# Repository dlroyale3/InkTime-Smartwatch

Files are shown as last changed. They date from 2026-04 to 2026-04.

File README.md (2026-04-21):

# Proiect InkTime - E-Paper Smartwatch (nRF52840)

## Descriere Generală
InkTime este un prototip hardware de smartwatch (dispozitiv wearable) proiectat de la zero, cu un focus absolut pe eficiența energetică (Ultra-Low Power) și miniaturizare. 
Creierul sistemului este SoC-ul **Nordic nRF52840**, capabil de conectivitate Bluetooth 5.0 LE. Dispozitivul interacționează cu utilizatorul printr-un ecran E-Paper de 3.3V (tehnologie bistabilă), butoane tactile și feedback haptic (motor liniar/ERM), fiind capabil să monitorizeze activitatea fizică prin intermediul unui accelerometru integrat.

---

## 1. Diagramă Bloc

Arhitectura hardware este centrată în jurul microcontrolerului, care acționează ca un Master I2C/SPI pentru toate perifericele, permițând controlul granular al stărilor de alimentare pentru fiecare modul în parte.

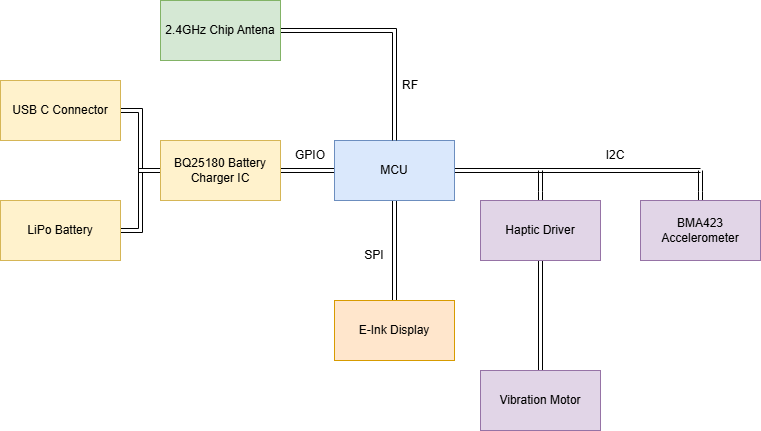
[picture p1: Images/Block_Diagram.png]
Diagrama Bloc InkTime


---

## 2. Bill of Materials (BOM) - Componente Principale

Pentru producția și asamblarea PCB-ului (PCBA), componentele au fost selectate pe baza disponibilității la producătorul JLCPCB (LCSC Parts) și a footprint-ului redus (QFN, BGA sau 0402/0201 pentru pasive).

| Componentă (Designator) | Rol în Sistem | Producător | Datasheet | Link JLCPCB |
| :--- | :--- | :--- | :--- | :--- |
| **nRF52840-QIAA** (U1) | Microcontroller & BLE Radio | Nordic Semi | [Datasheet](https://infocenter.nordicsemi.com/pdf/nRF52840_PS_v1.7.pdf) | [C145322](https://jlcpcb.com/partdetail/NordicSemicon-nRF52840QIAAR/C145322) |
| **BQ25180YBGR** (IC1) | LiPo Battery Charger | Texas Instruments | [Datasheet](https://www.ti.com/lit/ds/symlink/bq25180.pdf) | [C3166611](https://jlcpcb.com/partdetail/TexasInstruments-BQ25180YBGR/C3166611) |
| **MAX17048G+T10** (U3) | Fuel Gauge (Monitor Baterie) | Analog Devices | [Datasheet](https://www.analog.com/media/en/technical-documentation/data-sheets/MAX17048-MAX17049.pdf) | [C82806](https://jlcpcb.com/partdetail/Maxim_Integrated-MAX17048GT10/C82806) |
| **RT6160AWSC** (IC9) | DC/DC Buck-Boost Converter | Richtek | [Datasheet](https://www.richtek.com/assets/product_file/RT6160A/DS6160A-02.pdf) | [C2834316](https://jlcpcb.com/parts) |
| **BMA423 / BMA421** (IC3) | Accelerometru Triaxial (IMU) | Bosch Sensortec | [Datasheet](https://www.bosch-sensortec.com/media/boschsensortec/downloads/datasheets/bst-bma423-ds004.pdf) | [C283838](https://jlcpcb.com/partdetail/BoschSensortec-BMA423/C283838) |
| **DRV2605YZFR** (IC2) | Haptic Driver (LRA/ERM) | Texas Instruments | [Datasheet](https://www.ti.com/lit/ds/symlink/drv2605.pdf) | [C74431](https://jlcpcb.com/partdetail/TexasInstruments-DRV2605YZFR/C74431) |
| **2450AT18B100E** (ANT1)| Antenă Ceramică 2.4 GHz | Johanson Tech | [Datasheet](https://www.johansontechnology.com/datasheets/2450AT18B100/2450AT18B100.pdf) | [C210086](https://jlcpcb.com/partdetail/JohansonTechnology-2450AT18B100E/C210086) |

*(Notă: Componentele pasive - rezistențe și condensatori de 0201/0402, inductoarele de putere și conectorii USB-C/FPC se regăsesc detaliate în fișierul `BOM.csv` din folderul Manufacturing).*

---

## 3. Funcționalitate Hardware Detaliată

Sistemul a fost împărțit în mai multe subsisteme, optimizate pentru a permite oprirea alimentării (Power Gating) atunci când nu sunt utilizate.

### 3.1. Procesare și Radio (nRF52840)
MCU-ul rulează la o tensiune stabilizată de 3.3V. Pentru a menține timing-ul BLE și RTC-ul (Real Time Clock) cu un consum de doar ~1.5µA, a fost integrat un cristal extern de 32.768 kHz (`X2`). Conexiunea radio se face printr-o rețea Pi-Matching către antena ceramică de 2.4GHz.

### 3.2. Magistrala I2C și Senzorii
Toate perifericele de monitorizare și input folosesc o magistrală comună **I2C** (Fast Mode - 400kHz), echipată cu rezistențe de pull-up de 10kΩ.
* **BMA423 (IMU - 0x18):** Configurabil să ruleze algoritmul de *step-counting* intern. Nu ține MCU-ul treaz; trimite un semnal pe pinul `IMU_INT1` doar când detectează pași sau gesturi (Tilt-to-Wake).
* **MAX17048 (Fuel Gauge - 0x36):** Estimează starea bateriei (State of Charge) fără a necesita o rezistență de șunt (care ar irosi energie), folosind algoritmul ModelGauge. Poate genera o alertă hardware (`ALERT`) când bateria scade sub un prag definit.
* **BQ25180 (Charger - 0x6A):** Negociază curentul de încărcare tras din portul USB-C (limitat software la 100mA - 300mA pentru a proteja celula LiPo mică).
* **DRV2605 (Haptic - 0x5A):** Conține o bibliotecă internă de forme de undă pentru vibrații. Este ținut în shutdown (consum <1µA) și activat doar la notificări prin pinul `HAPTIC_EN`.

### 3.3. Display-ul E-Paper (SPI)
Interfața vizuală folosește un panou bistabil conectat printr-un cablu FPC 24-pin.
* **Comunicația:** Se face via **SPI 4-wire** (doar TX/MOSI, deoarece ecranul nu trimite date înapoi, ci folosește un pin dedicat `EPD_BUSY` pentru a semnaliza starea).
* **Boost Circuit:** Deoarece cerneala electronică necesită tensiuni mari (VGH, VGL, +/- 15V) pentru a muta pigmenții, placa include circuitul de switching cu inductor de 68uH și diode Schottky MBR0530. Acest circuit este pornit exclusiv în secunda în care ecranul își dă refresh.

### 3.4. Calcule de Consum de Energie (Power Budget)
Eficiența proiectului se bazează pe regimul de funcționare *Duty-Cycled*. Estimarea autonomiei cu o baterie LiPo de **150 mAh**:

1. **Modul Deep Sleep (98% din timp):**
   * nRF52840 (System ON, RTC): ~1.5 µA
   * BMA423 (Low-power sensing): ~4 µA
   * BQ25180 + RT6160 (Quiescent): ~8 µA
   * Fuel Gauge (Hibernate): ~3 µA
   * Ecran E-Paper: 0 µA
   * **Total Sleep:** **~16.5 µA**

2. **Modul Activ (Evenimente periodice):**
   * Refresh Ecran (1 dată pe minut): ~8 mA timp de 1s.
   * Transmisie BLE: ~5 mA timp de 10ms.
   * **Consum Mediu Echivalent:** **~1.2 mA / oră** (incluzând spike-urile de refresh).

3. **Autonomie Teoretică:** `150 mAh / 1.2 mA ≈ 125 de ore (aprox. 5 zile)` de utilizare normală, cu potențial de extindere până la **săptămâni** dacă ecranul este actualizat doar la cerere (button press).

---

## 4. Alocarea Pinilor nRF52840 și Justificare

Rutarea pinilor (Pin Muxing) a fost aleasă strategic pentru a evita încrucișările pe PCB și pentru a grupa interfețele de mare viteză.

| Pin MCU | Funcție Atribuită | Tip Interfață | Justificarea Alegerii (Hardware Design) |
| :--- | :--- | :--- | :--- |
| **P0.00 / P0.01** | `XL1` / `XL2` | Analog | Pini dedicați hardware exclusiv pentru cristalul LFXO (32.768kHz). |
| **P0.06 / P0.07** | `SDA` / `SCL` | I2C (TWIM) | Plasați convenabil pe latura de jos a IC-ului, rutare directă spre grupul de senzori (Bottom). |
| **P0.08 / P1.08** | `IMU_INT1` / `IMU_INT2`| GPIO (Interrupt) | Intrări cu capacitate de *Wake-up*, conectate direct la accelerometru. |
| **P0.02 / P0.03** | `SCK` / `MOSI` | SPI (SPIM) | Alocați pentru a minimiza distanța fizică a traseelor de mare viteză către conectorul FPC al ecranului (partea dreaptă a plăcii). |
| **P0.17** | `EPD_BUSY` | GPIO (Input) | Citește flag-ul de busy de la ecran. Permite MCU-ului să doarmă între comenzile SPI. |
| **P1.06** | `HAPTIC_EN` | GPIO (Output) | Semnal digital simplu (Enable) pentru a tăia alimentarea driverului de vibrații. |
| **P1.01 / P1.02 / P1.03** | `SW_UP/DN/ENT` | GPIO (Input) | Pini configurați cu rezistențe de pull-up interne/externe pentru debounce-ul mecanic al butoanelor. |
| **SWDIO / SWDCLK** | Debug / Flash | SWD | Pini hardwired pentru programarea via conectorul TC2030-IDC. |

---

## 5. Design Log & PCB Layout (4-Layer Stackup)

PCB-ul a fost proiectat pe 4 straturi pentru a asigura plane solide de referință (GND), necesare disipării termice și integrității semnalului RF. 
S-a implementat o matrice de **Via Stitching** în jurul secțiunii de radiofrecvență și un decupaj (Polygon Cutout) pe toate cele 4 straturi sub antena Johanson, pentru a preveni atenuarea undelor electromagnetice.

* **Layer 1 (Top):** Găzduiește toate componentele SMD, planul de masă (GND) primar și traseele critice de scurtă distanță.
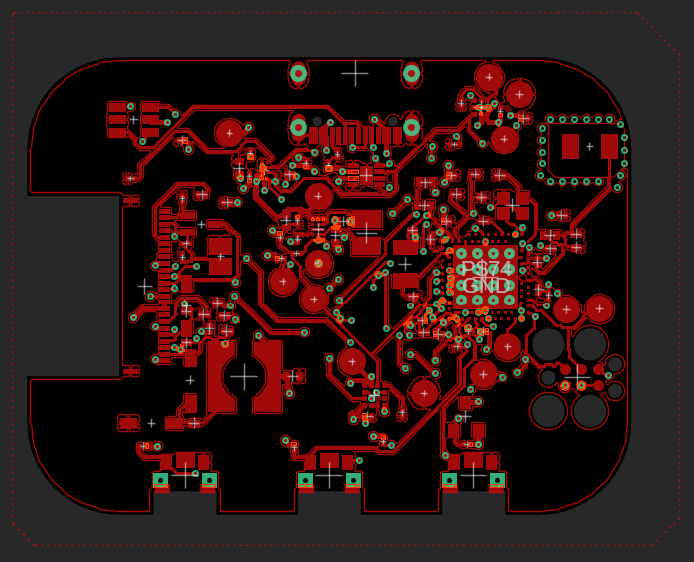
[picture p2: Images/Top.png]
Top Layer


* **Layer 2 (Route2 / Inner GND):** Strat intern dedicat exclusiv unui plan de masă continuu (Solid Ground Plane). Acesta oferă o cale de întoarcere curată și scurtă pentru curenți, esențială pentru ecranarea zgomotului (EMI) și performanța antenei.

* **Layer 3 (Route63 / Inner Power):** Strat intern dedicat rețelelor de distribuție a puterii (`3V3`, `VBUS`, `VBAT`, `VREG`). Traseele au o lățime minimă de 0.3mm pentru a menține o impedanță redusă și a preveni căderile de tensiune la solicitări tranzitorii.
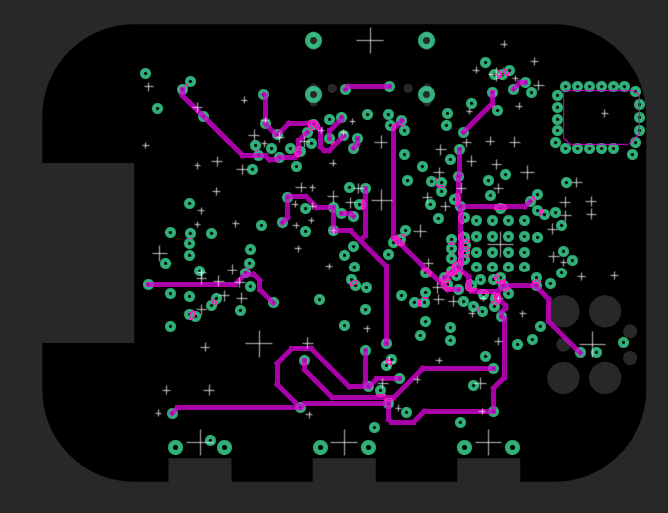
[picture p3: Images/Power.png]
Power Layer


* **Layer 4 (Bottom):** Utilizat preponderent pentru rutarea magistralelor de date (ex: `I2C`) și pentru realizarea conexiunilor lungi care ar fi aglomerat fața Top. Dispune, de asemenea, de propriul plan de masă auxiliar.
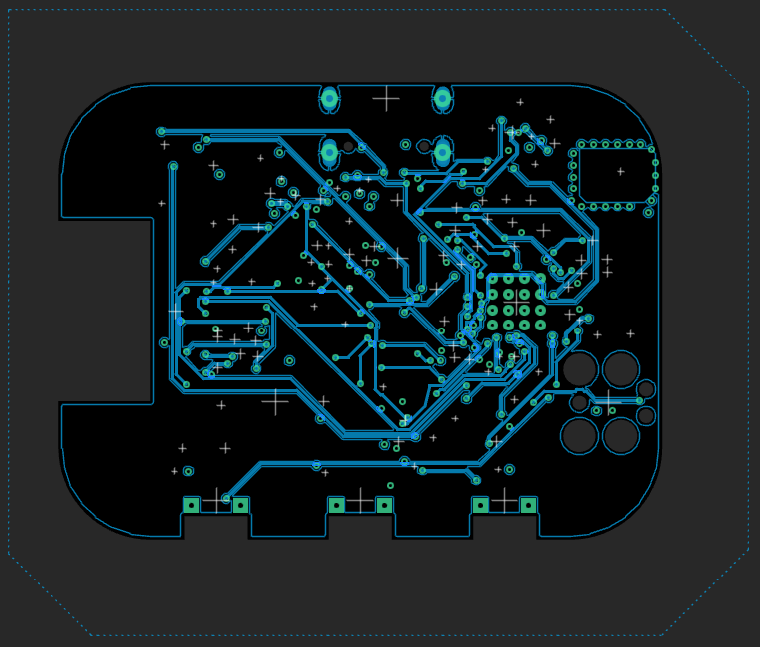
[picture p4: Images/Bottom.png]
Bottom Layer


### Testabilitate și Producție
Placa dispune de **Test Pad-uri** dedicate pentru toate semnalele critice (`3V3`, `VBAT`, `SDA`, `SCL`, `SWDIO`), etichetate clar pe layer-ul de Silkscreen, permițând depanarea facilă cu osciloscopul sau analizorul logic după asamblare.
### Testabilitate și Producție
Placa dispune de **Test Pad-uri** dedicate pentru toate semnalele critice (`3V3`, `VBAT`, `SDA`, `SCL`, `SWDIO`), etichetate clar pe layer-ul de Silkscreen, permițând depanarea facilă cu osciloscopul sau analizorul logic după asamblare.

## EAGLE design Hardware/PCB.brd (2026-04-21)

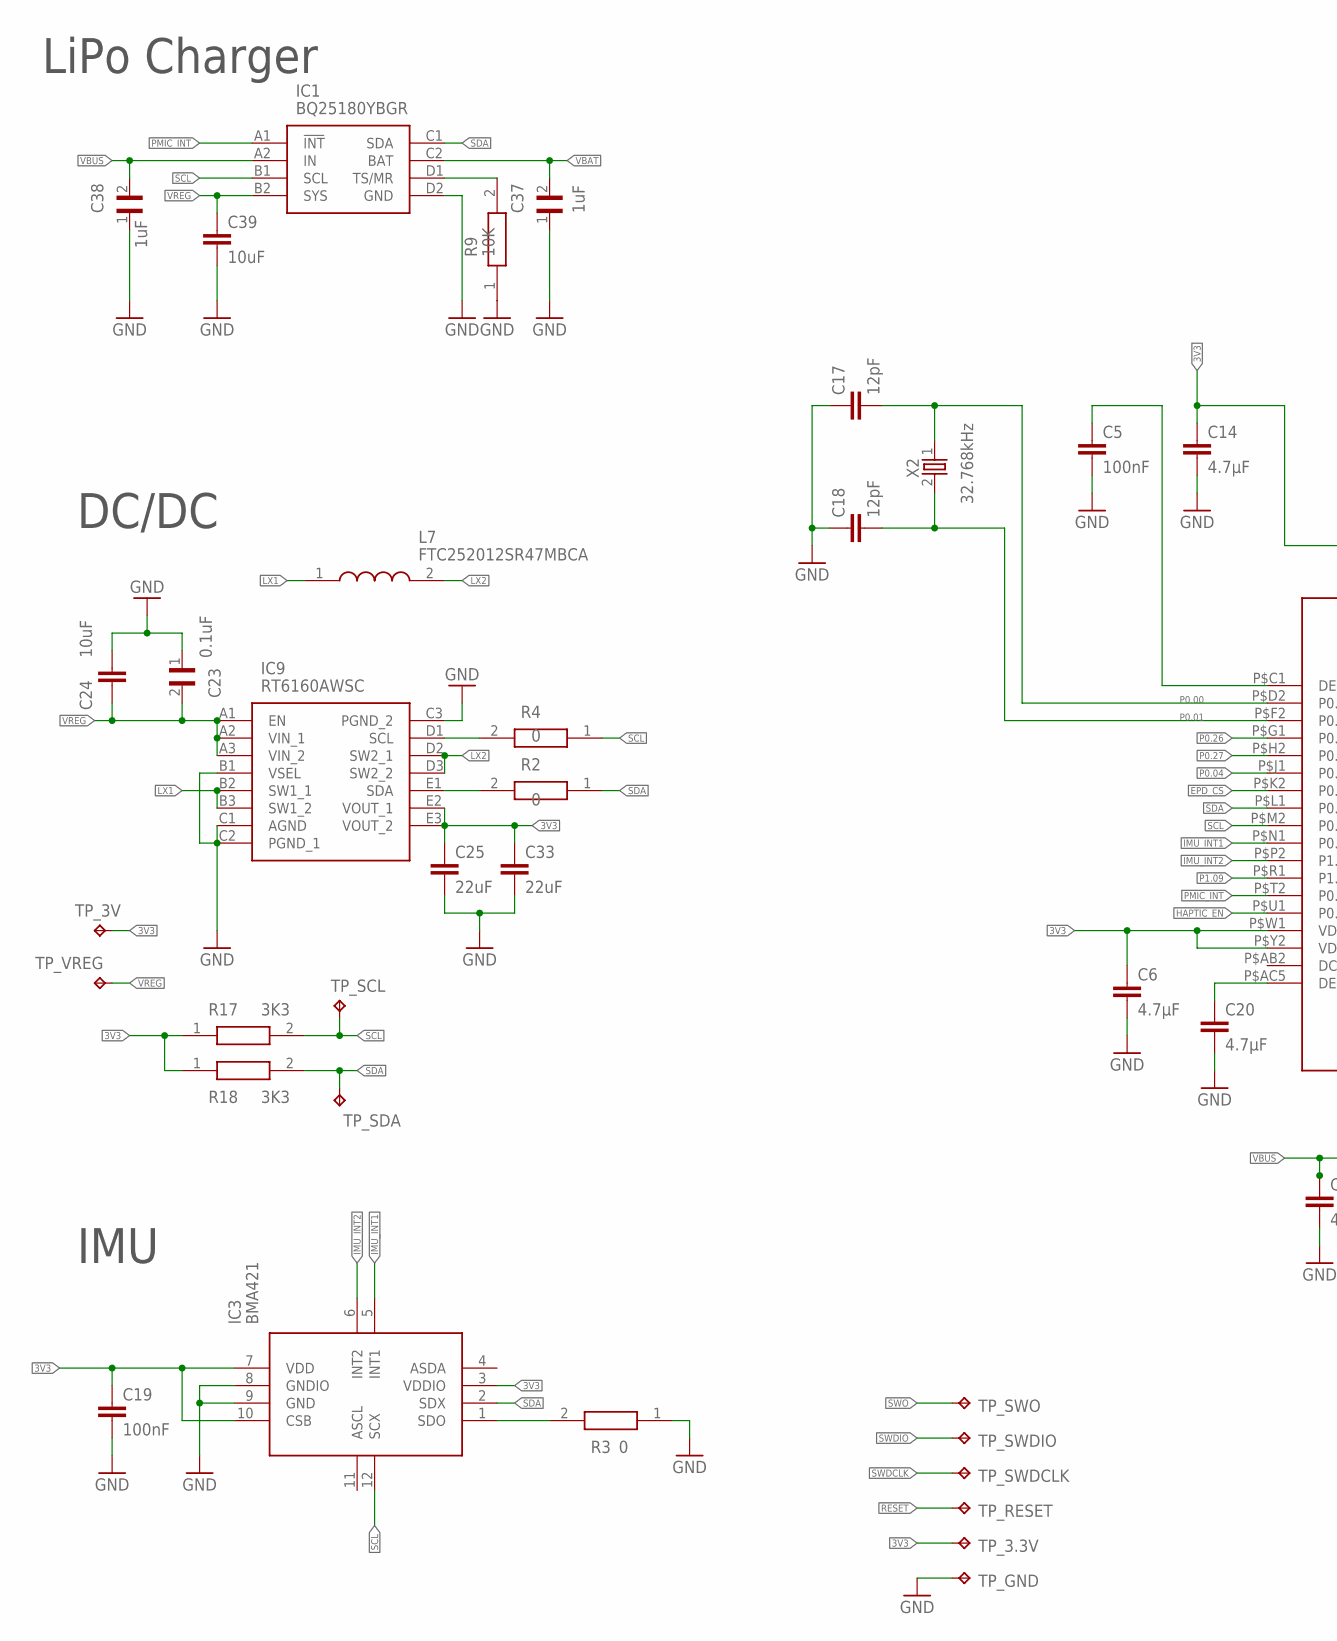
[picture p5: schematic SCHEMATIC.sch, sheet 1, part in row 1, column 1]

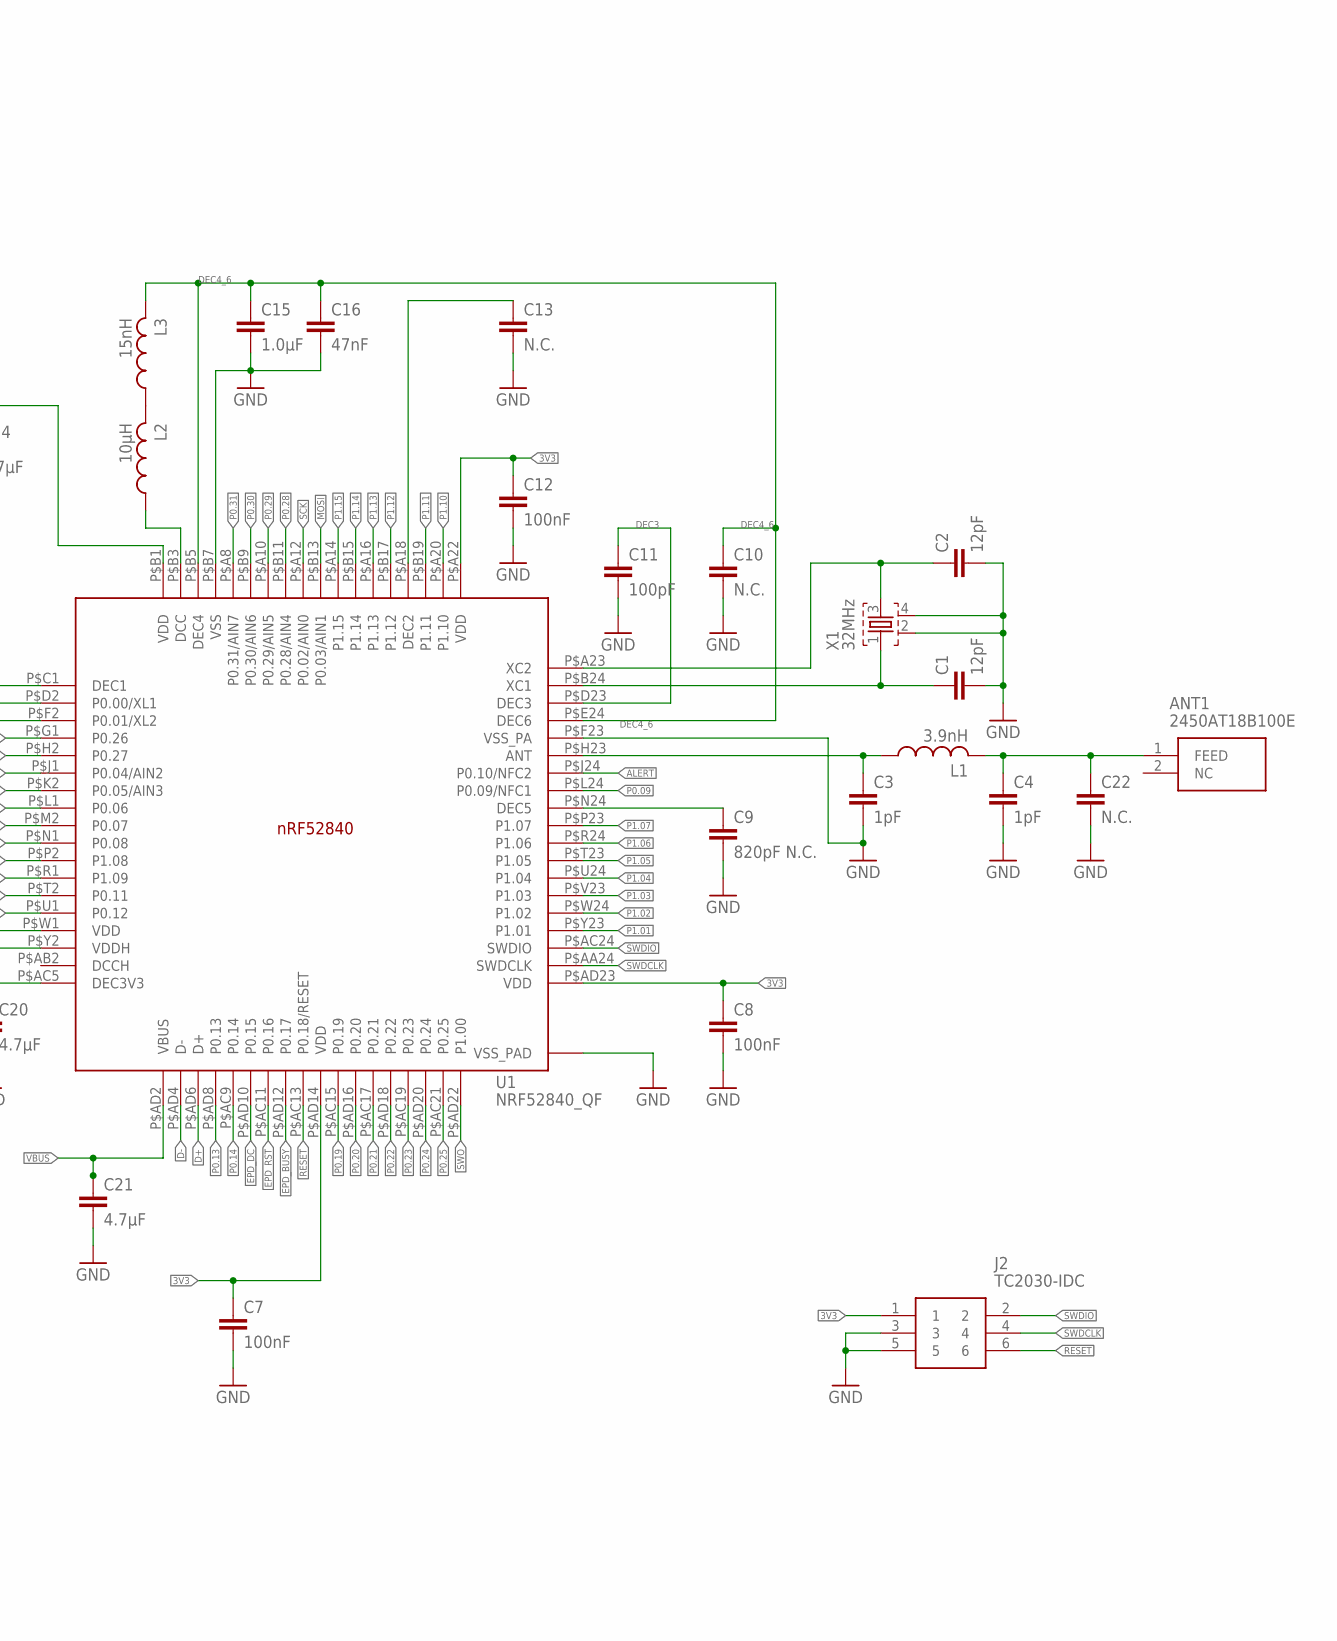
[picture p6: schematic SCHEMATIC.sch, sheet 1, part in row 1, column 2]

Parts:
ANT1: 2450AT18B100E; 2450AT18B100E_ANTC3216X140N
C1, C2, C17, C18: 12pF; NORDIC_NRF_3_RESC0201_L
C3, C4: 1pF; NORDIC_NRF_3_RESC0201_L
C5, C7, C8, C12, C19: 100nF; NORDIC_NRF_3_RESC0201_L
C6, C14, C20, C21: 4.7µF; NORDIC_NRF_3_RESC0201_L
C9: 820pF N.C.; NORDIC_NRF_3_RESC0201_L
C10, C13, C22: N.C.; NORDIC_NRF_3_RESC0201_L
C11: 100pF; NORDIC_NRF_3_RESC0201_L
C15: 1.0µF; NORDIC_NRF_3_RESC0201_L
C16: 47nF; NORDIC_NRF_3_RESC0201_L
C23: 0.1uF; GRM011R60J152KE01L_1_0201
C24, C39: 10uF; NORDIC_NRF_3_RESC0402_L
C25, C33: 22uF; NORDIC_NRF_3_RESC0402_L
C37, C38: 1uF; GRM011R60J152KE01L_1_0201
IC1: BQ25180YBGR; BQ25180YBGR_BGA8C40P2X4_100X155X50
IC3: BMA421; BMA423_BMA423
IC9: RT6160AWSC; RT6160AWSC_BGA15C40P3X5_140X230X60
J2: TC2030-IDC; TC2030-IDC_TC2030IDC
L1: 3.9nH; NORDIC_NRF_2_RESC0402_L
L2: 10µH; NORDIC_NRF_2_RESC0402_L
L3: 15nH; NORDIC_NRF_2_RESC0402_L
L7: FTC252012SR47MBCA; MLP2016SR47MT0S1_INDC2016X100N
R2, R3, R4: 0; CPF0201D7K68C1_0201
R9: 10K; CPF0201D7K68C1_0201
R17, R18: 3K3; CPF0201D7K68C1_0201
TP_3.3V, TP_3V: HECTOR_WATCH_1_TPTP20R; HECTOR_WATCH_1_TP20R
TP_GND: HECTOR_WATCH_1_TPTP20R; HECTOR_WATCH_1_TP20R
TP_RESET: HECTOR_WATCH_1_TPTP20R; HECTOR_WATCH_1_TP20R
TP_SCL: HECTOR_WATCH_1_TPTP20R; HECTOR_WATCH_1_TP20R
TP_SDA: HECTOR_WATCH_1_TPTP20R; HECTOR_WATCH_1_TP20R
TP_SWDCLK: HECTOR_WATCH_1_TPTP20R; HECTOR_WATCH_1_TP20R
TP_SWDIO: HECTOR_WATCH_1_TPTP20R; HECTOR_WATCH_1_TP20R
TP_SWO: HECTOR_WATCH_1_TPTP20R; HECTOR_WATCH_1_TP20R
TP_VREG: HECTOR_WATCH_1_TPTP20R; HECTOR_WATCH_1_TP20R
U1: NRF52840_QF; NORDIC_NRF_4_AQFN50P700X700X85_HS-74N
X1: 32MHz; NORDIC_NRF_BT-XTAL_2016_N
X2: 32.768kHz; NORDIC_NRF_1_XTAL_3215_N

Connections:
3V3: C6.1, C7.1, C8.1, C12.1, C14.1, C19.1, C25.1, C33.1, IC3.3 (VDDIO), IC3.7 (VDD), IC3.10 (CSB), IC9.E2 (VOUT_1), IC9.E3 (VOUT_2), J2.1, R17.1, R18.1, TP_3.3V.TP, TP_3V.TP, U1.P$A22 (VDD), U1.P$AD14 (VDD), U1.P$AD23 (VDD), U1.P$B1 (VDD), U1.P$W1 (VDD), U1.P$Y2 (VDDH); also elsewhere on the board
ALERT: U1.P$J24 (P0.10/NFC2); also elsewhere on the board
D+: U1.P$AD6 (D+); also elsewhere on the board
D-: U1.P$AD4 (D-); also elsewhere on the board
DEC3: C11.1, U1.P$D23 (DEC3)
DEC4_6: C10.1, C15.1, C16.1, L3.2, U1.P$B5 (DEC4), U1.P$E24 (DEC6)
EPD_BUSY: U1.P$AD12 (P0.17); also elsewhere on the board
EPD_CS: U1.P$K2 (P0.05/AIN3); also elsewhere on the board
EPD_DC: U1.P$AD10 (P0.15); also elsewhere on the board
EPD_RST: U1.P$AC11 (P0.16); also elsewhere on the board
GND: C1.2, C2.2, C3.2, C4.2, C5.2, C6.2, C7.2, C8.2, C9.2, C10.2, C11.2, C12.2, C13.2, C14.2, C15.2, C16.2, C17.1, C18.1, C19.2, C20.2, C21.2, C22.2, C23.1, C24.1, C25.2, C33.2, C37.1, C38.1, C39.2, IC1.D2 (GND), IC3.8 (GNDIO), IC3.9 (GND), IC9.B1 (VSEL), IC9.C1 (AGND), IC9.C2 (PGND_1), IC9.C3 (PGND_2), J2.3, J2.5, R3.1, R9.1, TP_GND.TP, U1.P$74 (VSS_PAD), U1.P$75 (VSS_PAD), U1.P$76 (VSS_PAD), U1.P$77 (VSS_PAD), U1.P$78 (VSS_PAD), U1.P$79 (VSS_PAD), U1.P$80 (VSS_PAD), U1.P$81 (VSS_PAD), U1.P$82 (VSS_PAD), U1.P$83 (VSS_PAD), U1.P$84 (VSS_PAD), U1.P$85 (VSS_PAD), U1.P$86 (VSS_PAD), U1.P$87 (VSS_PAD), U1.P$88 (VSS_PAD), U1.P$89 (VSS_PAD), U1.P$90 (VSS_PAD), U1.P$B7 (VSS), U1.P$F23 (VSS_PA), X1.2, X1.4; also elsewhere on the board
HAPTIC_EN: U1.P$U1 (P0.12); also elsewhere on the board
IMU_INT1: IC3.5 (INT1), U1.P$N1 (P0.08)
IMU_INT2: IC3.6 (INT2), U1.P$P2 (P1.08)
LX1: IC9.B2 (SW1_1), IC9.B3 (SW1_2), L7.1
LX2: IC9.D2 (SW2_1), IC9.D3 (SW2_2), L7.2
MOSI: U1.P$B13 (P0.03/AIN1); also elsewhere on the board
unnamed: IC1.D1 (TS/MR), R9.2
unnamed: IC9.D1 (SCL), R4.2
unnamed: IC9.E1 (SDA), R2.2
unnamed: L2.2, L3.1
unnamed: L2.1, U1.P$B3 (DCC)
unnamed: C13.1, U1.P$A18 (DEC2)
unnamed: C5.1, U1.P$C1 (DEC1)
unnamed: C20.1, U1.P$AC5 (DEC3V3)
unnamed: C9.1, U1.P$N24 (DEC5)
unnamed: C3.1, L1.1, U1.P$H23 (ANT)
unnamed: ANT1.1 (FEED), C4.1, C22.1, L1.2
unnamed: C1.1, U1.P$B24 (XC1), X1.1
unnamed: C2.1, U1.P$A23 (XC2), X1.3
unnamed: IC3.1 (SDO), R3.2
P0.00: C17.2, U1.P$D2 (P0.00/XL1), X2.1
P0.01: C18.2, U1.P$F2 (P0.01/XL2), X2.2
P0.04: U1.P$J1 (P0.04/AIN2)
P0.09: U1.P$L24 (P0.09/NFC1)
P0.13: U1.P$AD8 (P0.13); also elsewhere on the board
P0.14: U1.P$AC9 (P0.14); also elsewhere on the board
P0.19: U1.P$AC15 (P0.19)
P0.20: U1.P$AD16 (P0.20)
P0.21: U1.P$AC17 (P0.21)
P0.22: U1.P$AD18 (P0.22)
P0.23: U1.P$AC19 (P0.23)
P0.24: U1.P$AD20 (P0.24)
P0.25: U1.P$AC21 (P0.25)
P0.26: U1.P$G1 (P0.26)
P0.27: U1.P$H2 (P0.27)
P0.28: U1.P$B11 (P0.28/AIN4)
P0.29: U1.P$A10 (P0.29/AIN5)
P0.30: U1.P$B9 (P0.30/AIN6)
P0.31: U1.P$A8 (P0.31/AIN7)
P1.01: U1.P$Y23 (P1.01); also elsewhere on the board
P1.02: U1.P$W24 (P1.02); also elsewhere on the board
P1.03: U1.P$V23 (P1.03)
P1.04: U1.P$U24 (P1.04)
P1.05: U1.P$T23 (P1.05)
P1.06: U1.P$R24 (P1.06)
P1.07: U1.P$P23 (P1.07)
P1.09: U1.P$R1 (P1.09)
P1.10: U1.P$A20 (P1.10)
P1.11: U1.P$B19 (P1.11)
P1.12: U1.P$B17 (P1.12)
P1.13: U1.P$A16 (P1.13)
P1.14: U1.P$B15 (P1.14)
P1.15: U1.P$A14 (P1.15)
PMIC_INT: IC1.A1 (!INT), U1.P$T2 (P0.11)
RESET: J2.6, TP_RESET.TP, U1.P$AC13 (P0.18/RESET)
SCK: U1.P$A12 (P0.02/AIN0); also elsewhere on the board
SCL: IC1.B1 (SCL), IC3.12 (SCX), R4.1, R17.2, TP_SCL.TP, U1.P$M2 (P0.07); also elsewhere on the board
SDA: IC1.C1 (SDA), IC3.2 (SDX), R2.1, R18.2, TP_SDA.TP, U1.P$L1 (P0.06); also elsewhere on the board
SWDCLK: J2.4, TP_SWDCLK.TP, U1.P$AA24 (SWDCLK)
SWDIO: J2.2, TP_SWDIO.TP, U1.P$AC24 (SWDIO)
SWO: TP_SWO.TP, U1.P$AD22 (P1.00)
VBAT: C37.2, IC1.C2 (BAT); also elsewhere on the board
VBUS: C21.1, C38.2, IC1.A2 (IN), U1.P$AD2 (VBUS); also elsewhere on the board
VREG: C23.2, C24.2, C39.1, IC1.B2 (SYS), IC9.A1 (EN), IC9.A2 (VIN_1), IC9.A3 (VIN_2), TP_VREG.TP

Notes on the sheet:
LiPo Charger
DC/DC
IMU

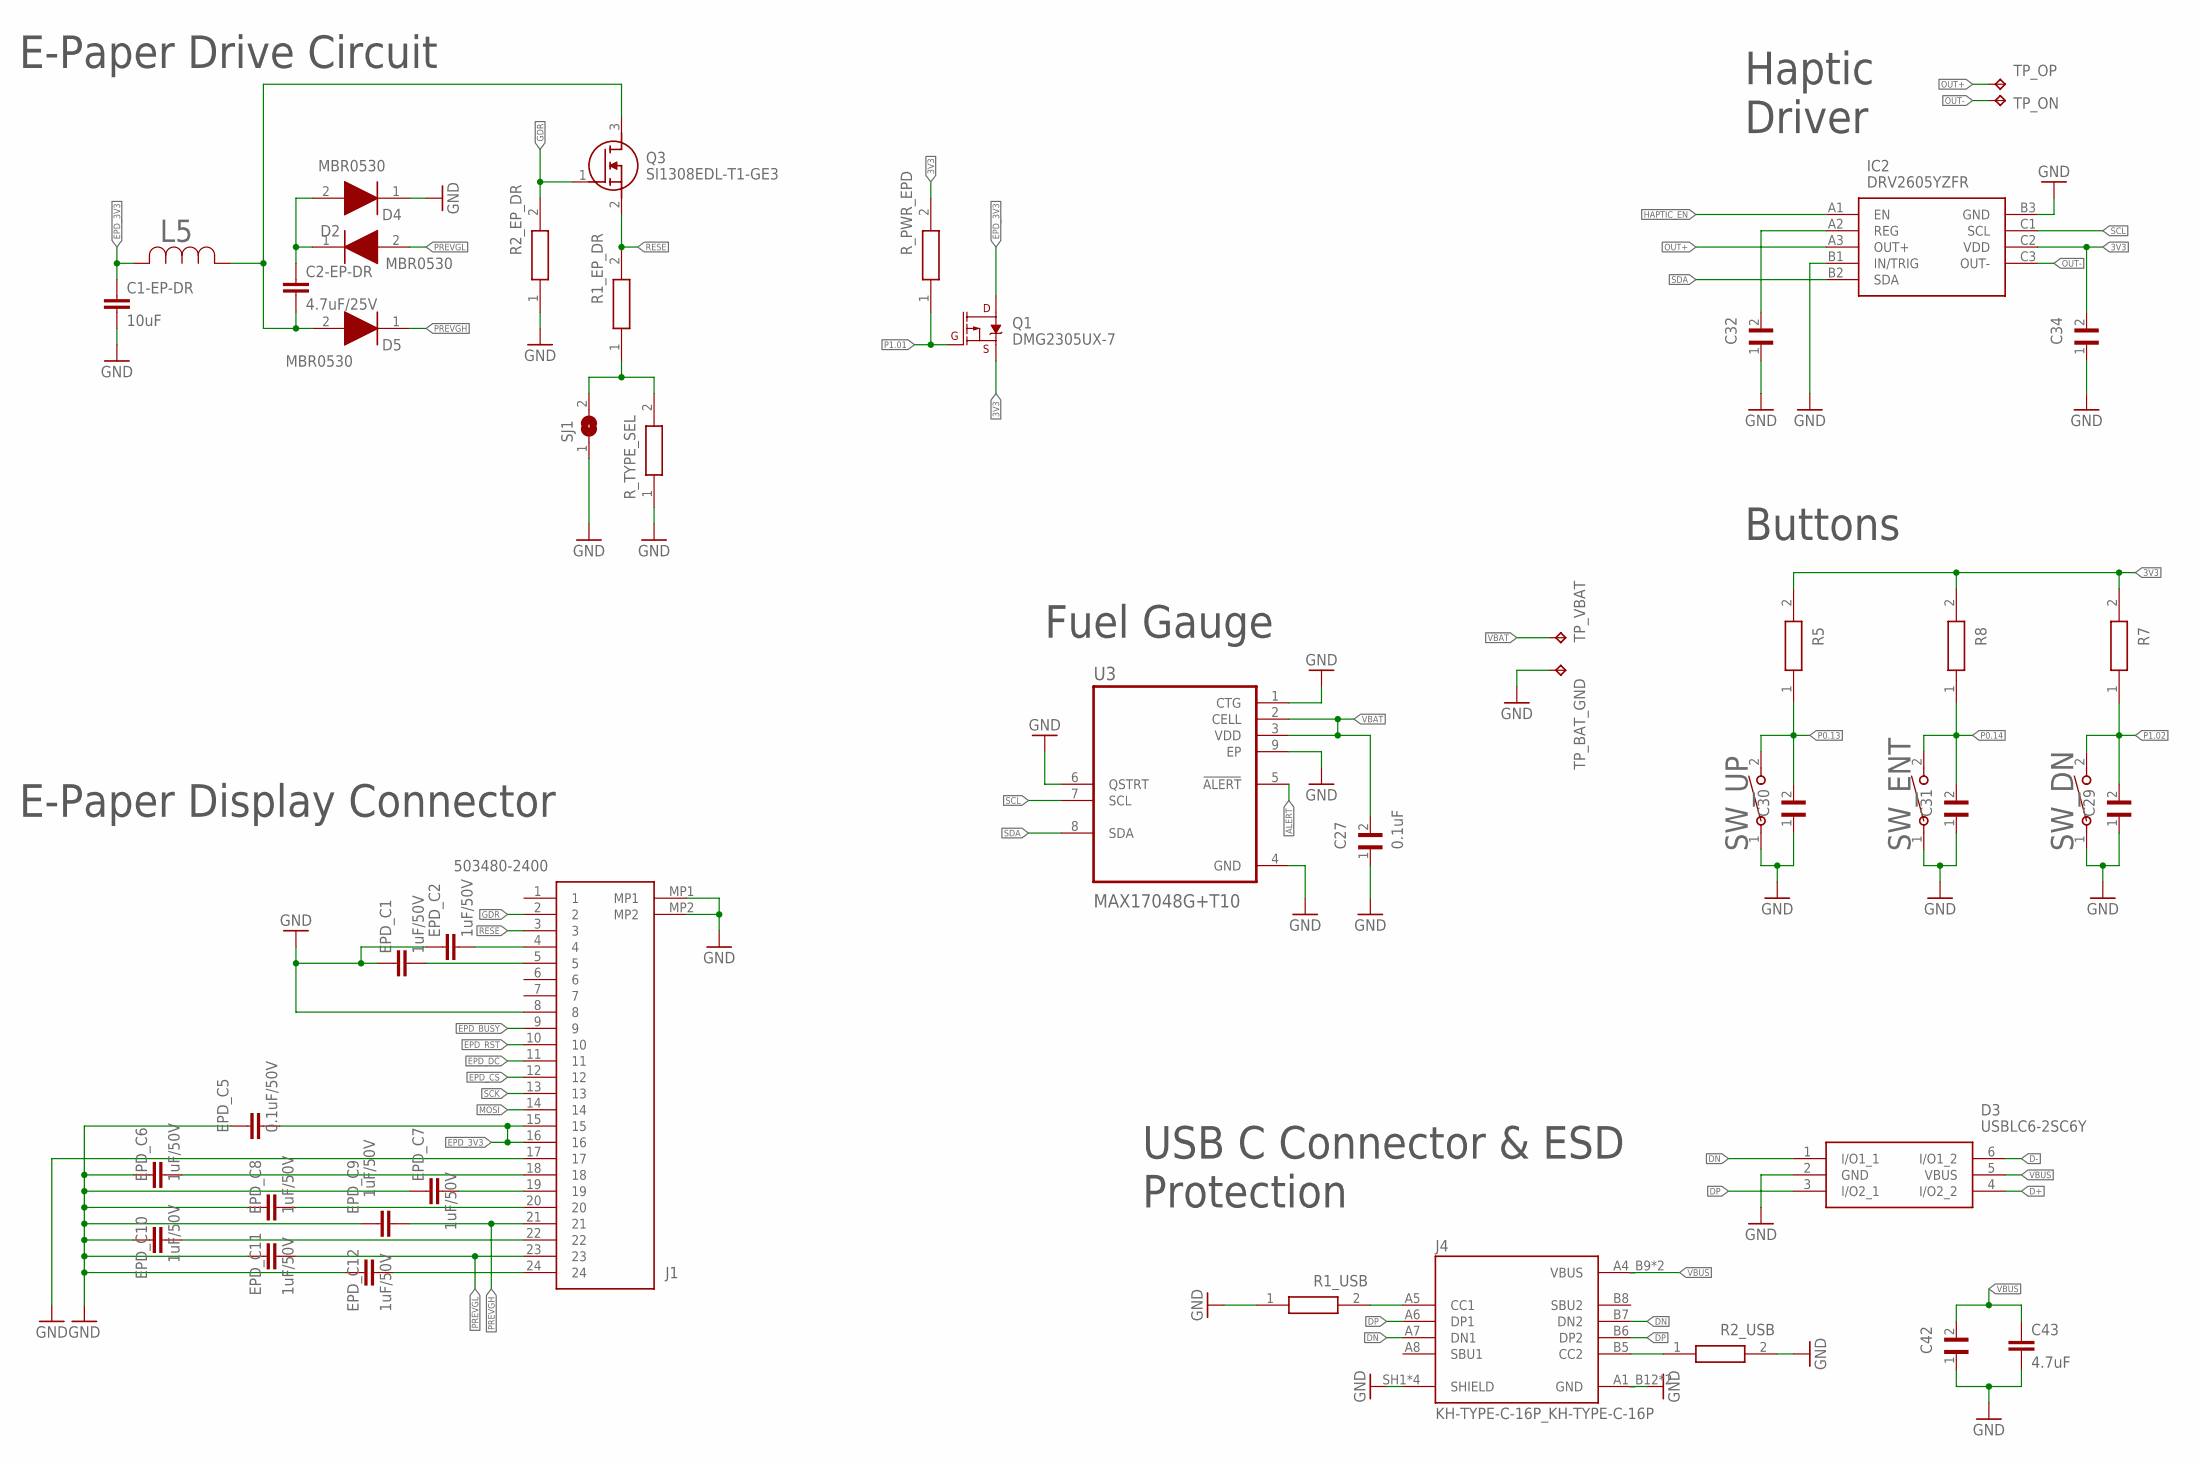
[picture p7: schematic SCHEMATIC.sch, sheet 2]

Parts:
C1-EP-DR: 10uF; NORDIC_NRF_3_RESC0402_L
C2-EP-DR: 4.7uF/25V; NORDIC_NRF_3_RESC0201_L
C27, C34, C42: 0.1uF; GRM011R60J152KE01L_1_0201
C29, C30, C31, C32: 1uF; GRM011R60J152KE01L_1_0201
C43: 4.7uF; NORDIC_NRF_3_RESC0201_L
D2, D4, D5: MBR0530; ESP32_C6_LIBRARY_5_SOD3716X135N
D3: USBLC6-2SC6Y; ESP32_C6_LIBRARY_3_SOT95P280X145-6N
EPD_C1, EPD_C2, EPD_C6, EPD_C7, EPD_C8, EPD_C9, EPD_C10, EPD_C11, EPD_C12: 1uF/50V; NORDIC_NRF_3_RESC0201_L
EPD_C5: 0.1uF/50V; NORDIC_NRF_3_RESC0201_L
IC2: DRV2605YZFR; DRV2605YZFR_BGA9C50P3X3_144X144X62
J1: 503480-2400; 503480-2400_5034802400
J4: KH-TYPE-C-16P_KH-TYPE-C-16P; KH-TYPE-C-16P_KINGHELM_KH-TYPE-C-16P
L5: ESP32_C6_LIBRARY_2_744043680IND_4828-WE-TPC_WRE; ESP32_C6_LIBRARY_2_IND_4828-WE-TPC_WRE
Q1: DMG2305UX-7; ESP32_C6_LIBRARY_4_ESP32_C6_LIBRARY_4_ESP32_C6_LIBRARY_4_ES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
Q3: SI1308EDL-T1-GE3; ESP32_C6_LIBRARY_6_SOT65P210X110-3N
R1_EP_DR: 0.47; CPF0201D7K68C1_0201
R1_USB, R2_USB: 5K1; CPF0201D7K68C1_0201
R2_EP_DR, R5, R7, R8: 10K; CPF0201D7K68C1_0201
R_PWR_EPD: 10K; CPF0201D7K68C1_0201
R_TYPE_SEL: 2.2; CPF0201D7K68C1_0201
SJ1: ESP32_C6_LIBRARY_7_JUMPER_SJ
SW_DN: 2025-10-22_07-23-44_LIBRARY_EVP-AKE31ASW_EVP-AKE3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; 2025-10-22_07-23-44_LIBRARY_SW_EVP-AKE31A_PAN
SW_ENT: 2025-10-22_07-23-44_LIBRARY_EVP-AKE31ASW_EVP-AKE3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; 2025-10-22_07-23-44_LIBRARY_SW_EVP-AKE31A_PAN
SW_UP: 2025-10-22_07-23-44_LIBRARY_EVP-AKE31ASW_EVP-AKE3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; 2025-10-22_07-23-44_LIBRARY_SW_EVP-AKE31A_PAN
TP_BAT_GND: HECTOR_WATCH_1_TPTP20R; HECTOR_WATCH_1_TP20R
TP_ON: HECTOR_WATCH_1_TPTP20R; HECTOR_WATCH_1_TP20R
TP_OP: HECTOR_WATCH_1_TPTP20R; HECTOR_WATCH_1_TP20R
TP_VBAT: HECTOR_WATCH_1_TPTP20R; HECTOR_WATCH_1_TP20R
U3: MAX17048G+T10; ESP32_C6_LIBRARY_SON50P200X200X80-9N

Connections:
3V3: C34.2, IC2.C2 (VDD), Q1.2 (S), R5.2, R7.2, R8.2, R_PWR_EPD.2; also elsewhere on the board
ALERT: U3.5 (!ALERT); also elsewhere on the board
D+: D3.4 (I/O2_2); also elsewhere on the board
D-: D3.6 (I/O1_2); also elsewhere on the board
DN: D3.1 (I/O1_1), J4.A7 (DN1), J4.B7 (DN2)
DP: D3.3 (I/O2_1), J4.A6 (DP1), J4.B6 (DP2)
EPD_3V3: C1-EP-DR.1, EPD_C5.2, J1.15, J1.16, L5.2, Q1.3 (D)
EPD_BUSY: J1.9; also elsewhere on the board
EPD_CS: J1.12; also elsewhere on the board
EPD_DC: J1.11; also elsewhere on the board
EPD_RST: J1.10; also elsewhere on the board
GDR: J1.2, Q3.1 (G), R2_EP_DR.2
GND: C1-EP-DR.2, C27.1, C29.1, C30.1, C31.1, C32.1, C34.1, C42.1, C43.2, D3.2 (GND), D4.1 (K), EPD_C1.1, EPD_C2.1, EPD_C5.1, EPD_C6.1, EPD_C7.1, EPD_C8.1, EPD_C9.1, EPD_C10.1, EPD_C11.1, EPD_C12.1, IC2.B1 (IN/TRIG), IC2.B3 (GND), J1.8, J1.17, J1.MP1, J1.MP2, J4.A1_B12 (GND), J4.A12_B1 (GND), J4.SH1 (SHIELD), J4.SH2 (SHIELD), J4.SH3 (SHIELD), J4.SH4 (SHIELD), R1_USB.1, R2_EP_DR.1, R2_USB.2, R_TYPE_SEL.1, SJ1.1, SW_DN.1, SW_ENT.1, SW_UP.1, TP_BAT_GND.TP, U3.1 (CTG), U3.4 (GND), U3.6 (QSTRT), U3.9 (EP); also elsewhere on the board
HAPTIC_EN: IC2.A1 (EN); also elsewhere on the board
MOSI: J1.14; also elsewhere on the board
unnamed: C2-EP-DR.2, D5.2 (A), L5.1, Q3.3 (D)
unnamed: C2-EP-DR.1, D2.1 (K), D4.2 (A)
unnamed: R1_EP_DR.1, R_TYPE_SEL.2, SJ1.2
unnamed: EPD_C2.2, J1.4
unnamed: EPD_C1.2, J1.5
unnamed: EPD_C7.2, J1.19
unnamed: EPD_C12.2, J1.24
unnamed: EPD_C8.2, J1.20
unnamed: EPD_C6.2, J1.18
unnamed: EPD_C10.2, J1.22
unnamed: J4.A5 (CC1), R1_USB.2
unnamed: J4.B5 (CC2), R2_USB.1
unnamed: C32.2, IC2.A2 (REG)
OUT+: IC2.A3 (OUT+), TP_OP.TP
OUT-: IC2.C3 (OUT-), TP_ON.TP
P0.13: C30.2, R5.1, SW_UP.2; also elsewhere on the board
P0.14: C31.2, R8.1, SW_ENT.2; also elsewhere on the board
P1.01: Q1.1 (G), R_PWR_EPD.1; also elsewhere on the board
P1.02: C29.2, R7.1, SW_DN.2; also elsewhere on the board
PREVGH: D5.1 (K), EPD_C9.2, J1.21
PREVGL: D2.2 (A), EPD_C11.2, J1.23
RESE: J1.3, Q3.2 (S), R1_EP_DR.2
SCK: J1.13; also elsewhere on the board
SCL: IC2.C1 (SCL), U3.7 (SCL); also elsewhere on the board
SDA: IC2.B2 (SDA), U3.8 (SDA); also elsewhere on the board
VBAT: C27.2, TP_VBAT.TP, U3.2 (CELL), U3.3 (VDD); also elsewhere on the board
VBUS: C42.2, C43.1, D3.5 (VBUS), J4.A4_B9 (VBUS), J4.A9_B4 (VBUS); also elsewhere on the board

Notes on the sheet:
E-Paper Drive Circuit
E-Paper Display Connector
Fuel Gauge
USB C Connector & ESD Protection
Buttons
Haptic Driver

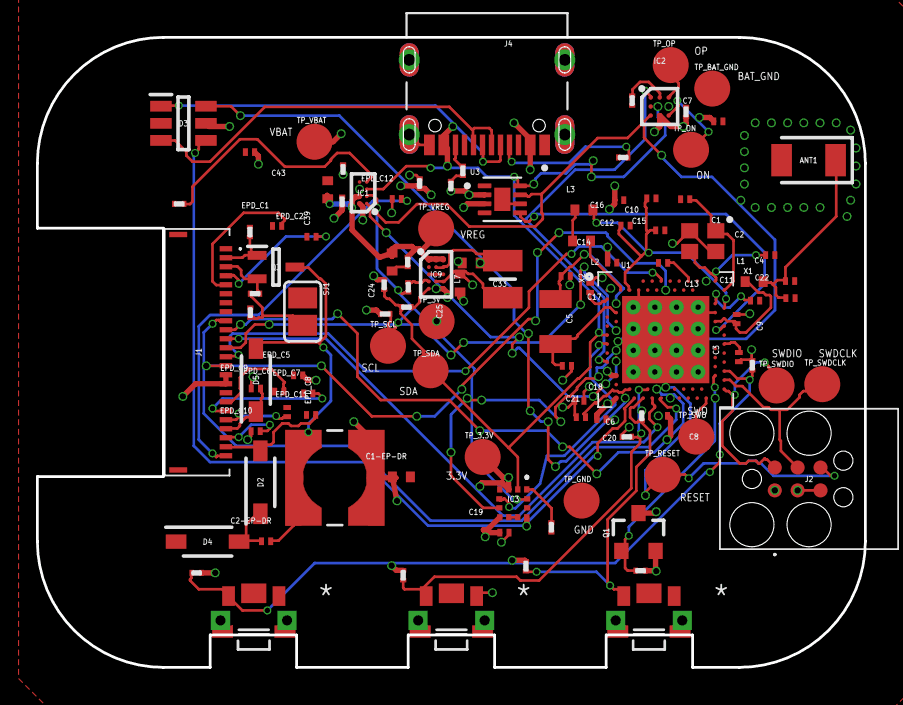
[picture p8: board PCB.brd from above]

Board: 4 copper layers, 46.0 x 35.0 mm, 105 parts (0 on the bottom side), 70 nets.

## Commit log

2026-04-16 Add files via upload
    Updated routing for PCB
    [BRD.brd, SCHEMATIC.sch]
2026-04-21 Revise README for InkTime E-Paper Smartwatch project
    Updated README with detailed project description, block diagram, BOM, hardware functionality, pin allocation, and PCB layout.
2026-04-21 Upload final release: Hardware, Manufacturing and 3D files
    [PCB.brd, SCHEMATIC.sch]

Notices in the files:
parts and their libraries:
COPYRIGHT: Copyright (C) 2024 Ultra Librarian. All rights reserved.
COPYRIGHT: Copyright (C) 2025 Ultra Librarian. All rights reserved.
